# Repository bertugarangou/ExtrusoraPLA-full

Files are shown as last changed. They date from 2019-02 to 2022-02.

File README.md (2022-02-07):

# Extrusora PLA - full

IMG-20180929-WA0008

Extrusora de PLA controlada amb Arduino Mega 2560.

### Material
És necessari el següent material en especial:
* **Arduino Mega 2650 (REV3).** Original o rèplica.
* **Extrusora muntada.** Tremuga, compartiment amb vis-sens-fi, boquilla, sistema de refrigeració i sistema de bobinatge.
* **Motors pas-a-pas NEMA 17 o 23.** Per la bobina i pel vis sens fi.
* **Bobina.** Per guardar el fil obtingut.
* **Font d'alimentació.** Per l'Arduino, ventiladors i motors i resistència, de 230V, 12V i 9V/5.05V.

També és recomanable entendre el llenguatge de programació C i C++ i el funcionament de la plataforma Arduino i Arduino IDE.

#### Peces en 3D

 Algunes peces han sigut dissenyades des de zero i impreses en 3D (PLA), es poden trobar a [Parts3D](/Parts). Per dissenyar-les, s'ha utilitzat el programa [Autodesk Inventor Pro 2018/2019](https://www.autodesk.com/products/inventor/overview) i [Fusion 360](https://www.autodesk.com/products/fusion-360/overview), per tant, els fitxers penjats estan en el format ".ipt" o ".dwg" si es tracta d'un esquema (plànol). A més a més, estan penjades les mateixes peces en el format ".stl" per si no es tenen els anteriors programes. Els fitxers ".stl" (STereoLithography/Standard Tessellation Language) permeten ser carregats per un programa com [Ultimaker Cura](https://ultimaker.com/en/products/ultimaker-cura-software) (codi obert) o [Simplify3D](https://www.simplify3d.com/) (no és de codi obert) entre d'altres per convertir-se en un format llegible per les impresores i especificar certes configuracions per l'impresió posterior.
 
Altres peces, les que estan en contacte amb zones calentes, estan fetes amb acer o alumini. Tot i així, els suports de la base són fets de fusta aglomerada.

Alerta: els fitxers s'han d'obrir amb la versió 2019 per no tenir errors de visualització. Els fitxers ".dwg" s'han d'obrir amb Innventor millor que amb AutoCAD. Els programes d'Autodesk són de llicència gratuita educativa.

## Referències

* [Github](https://github.com/bertugarangou/ExtrusoraPLA/) - Sistema al núvol
* [Arduino](https://www.arduino.cc/) - Software
* [Arduino LiquidCrystal Library](https://www.arduino.cc/en/Reference/LiquidCrystal) - LLibreria d'Arduino per LCD
* [Arduino Tasker Library](https://github.com/joysfera/arduino-tasker) - Llibreria d'Arduino per l'ús multi-tasca

## Autors

* **Albert Garangou Culebras** - *Autor principal del projecte*

## Llicència

[LICENSE.md](LICENSE.md)

## Reconeixaments

* *Tutor del Treball de Recerca* - **Jordi Fanals Oriol**

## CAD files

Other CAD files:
Parts/Esquemes/0. Base/Estructura base.dwg
Parts/Esquemes/1. Extrusora/suport motor-1.dwg
Parts/Esquemes/1. Extrusora/tremuja.ipt
Parts/Models/0. Base/Estructura base.ipt
Parts/Models/1. Ventiladors/Ventilador bobina - boca.ipt
Parts/Models/1. Ventiladors/Ventilador bobina - suport.ipt
Parts/Models/1. Ventiladors/Ventilador controladores - boca.ipt
Parts/Models/1. Ventiladors/Ventilador controladores - suport.ipt
Parts/Models/1. Ventiladors/Ventilador filament - boca.ipt
Parts/Models/1. Ventiladors/Ventilador filament - cosPETIT.ipt
Parts/Models/1. Ventiladors/Ventilador tub - cos.ipt
Parts/Models/1. Ventiladors/Ventilador tub - guies.ipt
Parts/Models/1. Ventiladors/ventilador emergència inferior.ipt
Parts/Models/1. Ventiladors/ventilador emergència superior.ipt
Parts/Models/2. Extrusora/Motor extrusora - suport.ipt
Parts/Models/3. Detector fil/Detector fil - base.ipt
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

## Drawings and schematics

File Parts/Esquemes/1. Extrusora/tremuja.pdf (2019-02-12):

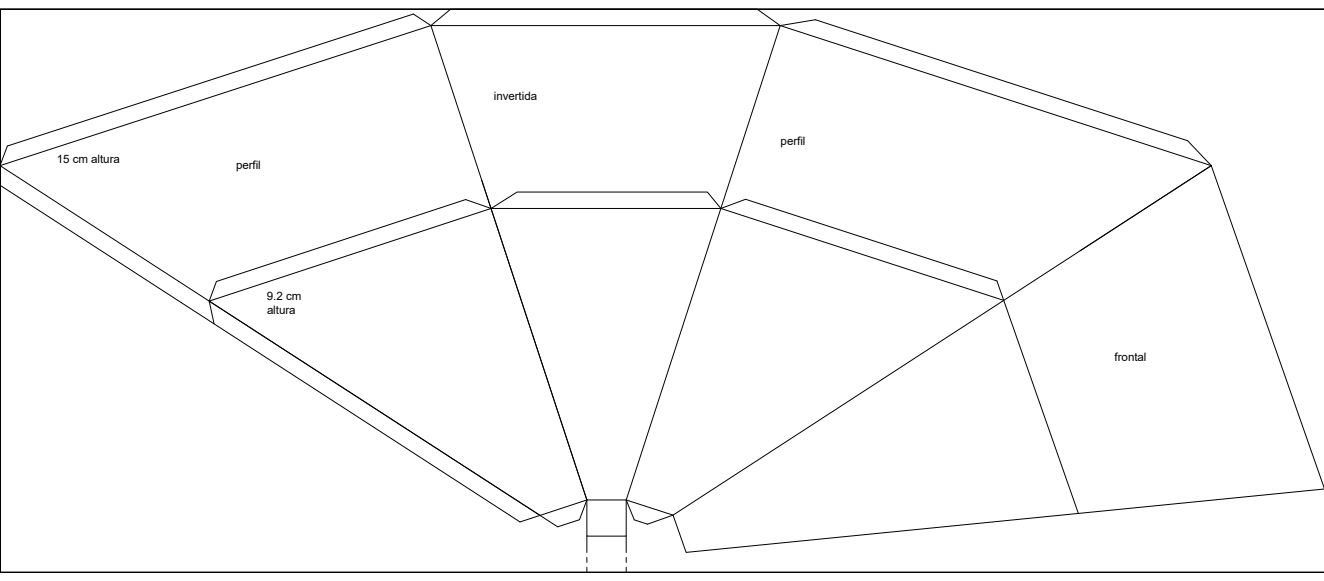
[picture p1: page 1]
rfil perfil; al 15 cm altura; 9.2 cm altura

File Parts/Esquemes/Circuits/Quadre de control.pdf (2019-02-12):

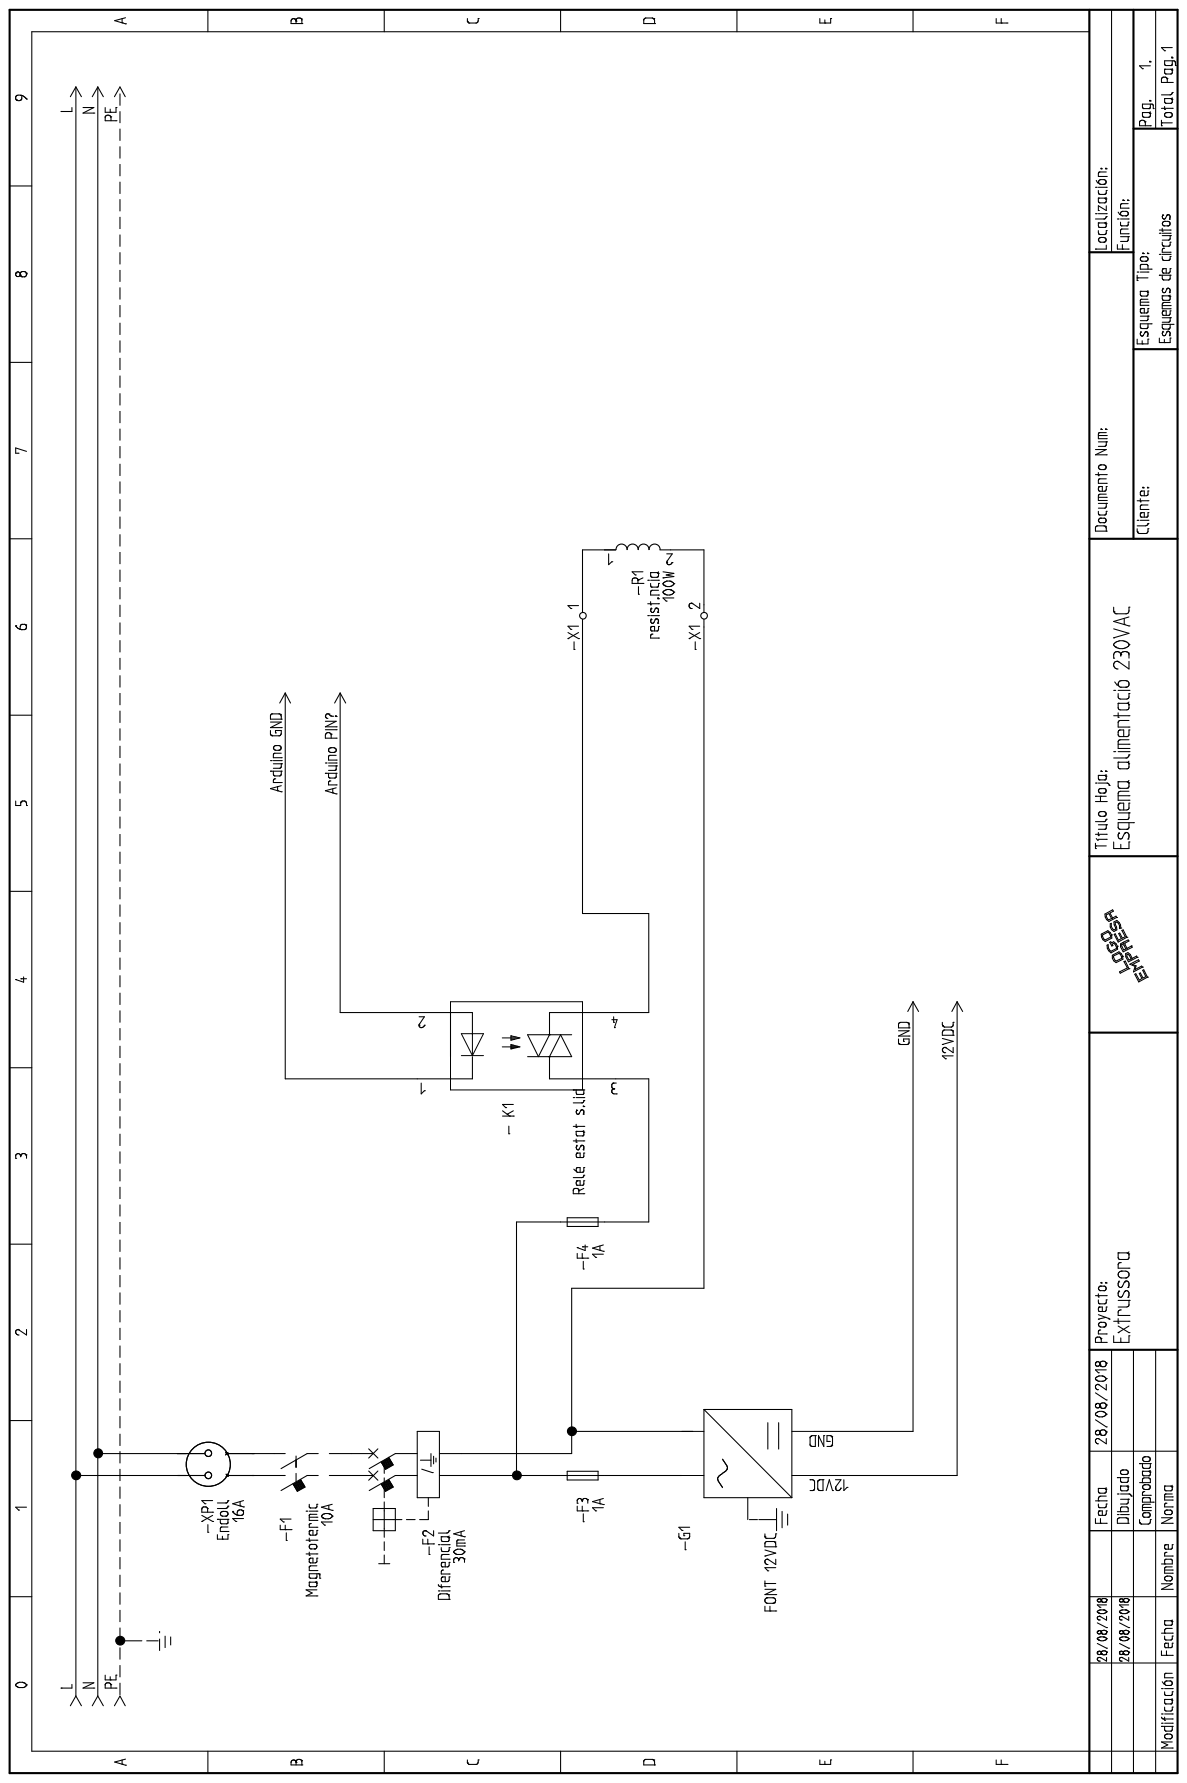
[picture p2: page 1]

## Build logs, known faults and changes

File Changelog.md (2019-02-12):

# Historial de versions

## Com funciona:
---
## Versió [NUMERO] (Data) - *CodeName*
 ## <No Funcional>

 ### Millores

  * Descripció
  * Descripció
      * Contingut

 ### Correccions
  * Descripció

 ### Errors coneguts
  * Descripció

 ### Més informació
  * "Commits"

---

## Versió 1 (15/10/2018) - *Inicial*

 ### Errors coneguts
  * El sensor IR detecta el fil per cualpa d'alguns llums d'habitacions.

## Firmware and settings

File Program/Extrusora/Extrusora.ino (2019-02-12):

/*
  Extrusora de PLA controlada per Arduino Mega 2560.

  Projecte:
  - https://github.com/bertugarangou/ExtrusoraPLA
  - Extrusora feta per Albert Garangou,
    com a Treball de Recerca a 2n de Batxillerat,
    curs 2018/2019, tutor: Jordi Fanals Oriol,
    codi amb Atom i Arduino-upload package.
  - Tots els drets reservats Albert Garangou Culebras (albertgarangou@gmail.com).
    Aquest codi és conegut com a "Proprietary software".
    Consulta el web origen per a més informació.
*/
/*+++++++++++++Llibreries++++++++++++++*/
#include <max6675.h>
MAX6675 tempSensorResistors(11, 12, 13);
MAX6675 tempSensorEnd(8, 9, 10);

#include <Wire.h>
#include <LiquidCrystal_I2C.h>
LiquidCrystal_I2C lcd(0x27, 16, 2); //PINS SDA i SCL lcd

/*+++++++++++++Llibreries++++++++++++++*/
/*++Declaració variables i constants+++*/
int const lcdUpdateFrequency = 250;  //1000-1500-x
int const tempReaderFrequency = 1000; //1000-1500-x
int const heaterFrequency = 0; //0 (instantari)-500-1000-x

int const INTFanFil = 6;
int const INTFanTube = 7;
int const relayFanFil = 52;
int const relayFanTube = 50;
int const STOPBtn = 30;
int const brunzidor = 51;
int const extruderStep = 25;
int const extruderDir = 26;
int const extruderEn = 28;
int const coilStep = 24;
int const coilDir = 27;
int const coilEn = 29;
int const filamentDetector = 36;
int const INTHeat = 53;
int const INTExtruder = 2;
int const INTExtruderRev = 3;
int const INTCoil = 4;
int const INTCoilRev = 5;
int const INTHeater = 49;
int const relayResistors = 32;

bool error = false;
bool canExtrude = false;
bool canCoil = false;

bool extrudingFwd = false;
bool extrudingRev = false;
bool coilingFwd = false;
bool coilingRev = false;

bool heatingPause = false;
bool heating = false;

bool canCoilByFilamentDetector = false;

int tempToShow;
float tempRest = 0.0;
float currentTempResistors = 0.0;
float currentTempEnd = 0.0;

float desiredTemp;
float desiredTempEnd;
float desiredTempResistors;

float tempResistors1 = 0.0;
float tempResistors2 = 0.0;
float tempResistors3 = 0.0;
float tempEnd1 = 0.0;
float tempEnd2 = 0.0;
float tempEnd3 = 0.0;
float finalTempEnd = 0.0;
float finalTempResistors = 0.0;

int const slowTempRange = 5;
int const tempMaxHot = -3; //-3
int tempResistorsRest;
int tempEndRest;

unsigned long ultimMillis_LCDMain = 0UL;
unsigned long ultimMillis_extruderStart = 0UL;
unsigned long ultimMillis_extruderStop = 0UL;
unsigned long ultimMillis_coilStart = 0UL;
unsigned long ultimMillis_coilStop = 0UL;
unsigned long ultimMillis_tempReader = 0UL;
unsigned long ultimMillis_heaterMain = 0UL;

int const extruderNEINSpeed = 6;
int const coilNEINSpeed = 20;

byte downArrow[8] = {
  B00100,
  B00100,
  B00100,
  B00100,
  B00100,
  B10101,
  B01110,
  B00100
};

byte upArrow[8] = {
  B00100,
  B01110,
  B10101,
  B00100,
  B00100,
  B00100,
  B00100,
  B00100
};

byte cross[8] = {
  B00000,
  B10001,
  B01010,
  B00100,
  B01010,
  B10001,
  B00000,
  B00000
};

byte check[8] = {
  B00000,
  B00000,
  B00001,
  B00010,
  B10100,
  B01000,
  B00000,
  B00000
};

byte rev[8] = {
  B00010,
  B00110,
  B01110,
  B11110,
  B01110,
  B00110,
  B00010,
  B00000
};

byte pause[8] = {
  B00000,
  B01010,
  B01010,
  B01010,
  B01010,
  B01010,
  B00000,
  B00000
};

/*++Declaració variables i constants+++*/
/*+++++++++++Declaracio funcions+++++++++++*/
void lcdController();
void fansController();
void extruderController();
void coilController();
void filamentDetectorFunction();
void heater();
void tempRead();
void errorProcedure();
void quickTempRead();
/*+++++++++++Declaracio funcions+++++++++++*/

void setup(){
  Serial.begin(9600); //inicia la depuració
  lcd.init();
  lcd.backlight();
  lcd.createChar(1, downArrow);
  lcd.createChar(2, upArrow);
  lcd.createChar(3, cross);
  lcd.createChar(4, check);
  lcd.createChar(5, rev);
  lcd.createChar(6, pause);

  lcd.clear();
  pinMode(INTFanFil, INPUT);
  pinMode(INTFanTube, INPUT);
  pinMode(STOPBtn, INPUT);
  pinMode(relayFanFil, OUTPUT);
  pinMode(relayFanTube, OUTPUT);
  pinMode(brunzidor, OUTPUT);
  pinMode(extruderStep, OUTPUT);
  pinMode(extruderDir, OUTPUT);
  pinMode(extruderEn, OUTPUT);
  pinMode(coilStep, OUTPUT);
  pinMode(coilDir, OUTPUT);
  pinMode(coilEn, OUTPUT);
  pinMode(filamentDetector, INPUT);
  pinMode(INTExtruder, INPUT);
  pinMode(INTExtruderRev, INPUT);
  pinMode(INTCoil, INPUT);
  pinMode(INTCoilRev, INPUT);
  pinMode(INTHeater, INPUT);
  pinMode(relayResistors, OUTPUT);
  digitalWrite(relayResistors, LOW);
}

void loop(){
 if(digitalRead(STOPBtn) == 0 || error == true){
  digitalWrite(brunzidor, HIGH);
  Serial.println("*****************************************");
  Serial.print("*   STOP");
  Serial.println(", entrant en mode emergència!   *");
  Serial.println("*                                       *");
  Serial.println("* NO DESCONECTAR FINS QUE ESTIGUI FRED! *");
  Serial.println("*****************************************");
  lcd.clear();
  lcd.print("!NO DESCONECTAR!");
  lcd.setCursor(9,1);
  lcd.print("ALERTA!");
  errorProcedure();
  while(true){//bucle infinit
  digitalWrite(brunzidor, LOW);
  lcd.noBacklight();
  quickTempRead();
  digitalWrite(brunzidor, HIGH);
  lcd.setCursor(0,1);
  lcd.print((int) finalTempResistors);
  lcd.print(char(223));
  lcd.print("/");
  lcd.print((int) finalTempEnd);
  lcd.print(char(223));
  lcd.backlight();
  delay(2000);
  }
 }
  else{ //funcionament estandart del programa (aka no hi ha cap error)
    lcdController();
    filamentDetectorFunction();
    fansController();
    tempRead();
    heater();
    extruderController();
    coilController();

  }
} //end

/*+++++++++++Definició funicons++++++++++++*/
void extruderController(){
  if (digitalRead(INTExtruder) == LOW && digitalRead(INTExtruderRev) == HIGH){//activat
    if(tempToShow > 169 && tempRest > -10){
      canCoil = true;
      if(millis() - ultimMillis_extruderStart >= extruderNEINSpeed){
        extrudingFwd = true;
        extrudingRev = false;
        digitalWrite(extruderStep, HIGH);
      if(millis() - ultimMillis_extruderStop >= extruderNEINSpeed){
        digitalWrite(extruderStep, LOW);
        ultimMillis_extruderStop = millis();
        ultimMillis_extruderStart = millis();
        }
      }
    }
  }
  else if(digitalRead(INTExtruder) == LOW && digitalRead(INTExtruderRev) == LOW){//invertit
    if(tempToShow > 169 && tempRest > -10){
      canCoil = false;
      if(millis() - ultimMillis_extruderStart >= extruderNEINSpeed){
        extrudingRev = true;
        extrudingFwd = false;
        digitalWrite(extruderDir, HIGH);
        digitalWrite(extruderStep, HIGH);
      if(millis() - ultimMillis_extruderStop >= extruderNEINSpeed){
        digitalWrite(extruderStep, LOW);
        digitalWrite(extruderDir, LOW);
        ultimMillis_extruderStop = millis();
        ultimMillis_extruderStart = millis();
        }
      }
    }
  }
  else{ //desactivat
    extrudingFwd = false;
    extrudingRev = false;
    canCoil = false;
  }
}

void coilController(){
  if (digitalRead(INTCoil) == LOW && digitalRead(INTCoilRev) == LOW){ // tots dos activats
    if(millis() - ultimMillis_coilStart >= coilNEINSpeed){
      coilingFwd = false;
      coilingRev = true;
      digitalWrite(coilStep, HIGH);
    if(millis() - ultimMillis_coilStop >= coilNEINSpeed){
      digitalWrite(coilStep, LOW);
      ultimMillis_coilStop = millis();
      ultimMillis_coilStart = millis();
      }
    }
  }
  else if(digitalRead(INTCoil) == LOW && digitalRead(INTCoilRev) == HIGH && canCoilByFilamentDetector == true){ // sense invertir direcció
    if(millis() - ultimMillis_coilStart >= coilNEINSpeed){
      coilingFwd = true;
      coilingRev = false;
      digitalWrite(coilDir, HIGH);
      digitalWrite(coilStep, HIGH);
      if(millis() - ultimMillis_coilStop >= coilNEINSpeed){
        digitalWrite(coilStep, LOW);
        digitalWrite(coilDir, LOW);
        ultimMillis_coilStop = millis();
        ultimMillis_coilStart = millis();
      }
    }
  }
  else{
    coilingFwd = false;
    coilingRev = false;
  }
}

void fansController(){
  if(digitalRead(INTFanFil) == LOW){ //quan s'activa l'interruptor adequat
    digitalWrite(relayFanFil, LOW); //activar relé ventilador
    //Serial.println("Ventilador: Filament **ON**");
  }
  else{ //sinó
    digitalWrite(relayFanFil, HIGH); //desactiva'l
    //Serial.println("Ventilador: Filament **OFF**");
  }

  if(digitalRead(INTFanTube) == LOW){  //si s'activa l'interruptor adequat
    digitalWrite(relayFanTube, LOW);  //activa el relé del ventilador
    //Serial.println("Ventilador: Extrusora **ON**");
  }
  else{ //sinó
    digitalWrite(relayFanTube, HIGH);  //desactiva'l
    //Serial.println("Ventilador: Extrusora **OFF**");
  }
}

void lcdController(){
  if(millis() - ultimMillis_LCDMain >= lcdUpdateFrequency){
    lcd.setCursor(0,0);
    lcd.print((int) tempToShow);
    lcd.print("/");
    lcd.print((int) desiredTemp);
    lcd.print(char(223));
    lcd.print("  ");

    if(canExtrude == true){ //estat general
      lcd.setCursor(10,0);
      lcd.print(" LLEST");
    }
    else if(canExtrude == false && heating == true){
      lcd.setCursor(10,0);
      lcd.print("ESPERA");
    }

    else{
      lcd.setCursor(10, 0);
      lcd.print(" PAUSA");
    }

    if(extrudingFwd == true){ //estat extrusor
      lcd.setCursor(0,1);
      lcd.print("E:");
      lcd.write(4);
      lcd.print(" ");
    }
    else if(extrudingRev == true){
      lcd.setCursor(0,1);
      lcd.print("E:");
      lcd.write(5);
      lcd.write(5);
    }
    else{
      lcd.setCursor(0,1);
      lcd.print("E:");
      lcd.write(3);
      lcd.print(" ");
    }

    if(coilingFwd == true){  //estat bobina
      lcd.setCursor(11,1);
      lcd.print("B:");
      lcd.write(4);
      lcd.print(" ");
    }
    else if(coilingRev == true){
      lcd.setCursor(11,1);
      lcd.print("B:");
      lcd.write(5);
      lcd.write(5);
    }
     else{
      lcd.setCursor(11,1);
      lcd.print("B:");
      lcd.write(3);
      lcd.print(" ");
    }

    if(heating == true && heatingPause == false){  //estat heating
      lcd.setCursor(6,1);
      lcd.print("H:");
      lcd.write(4);
    }
    else if(heating == true && heatingPause == true){
      lcd.setCursor(6,1);
      lcd.print("H:");
      lcd.write(6);
    }
    else{
      lcd.setCursor(6,1);
      lcd.print("H:");
      lcd.write(3);
    }


      if(coilingFwd == true){
      lcd.setCursor(15,1);
      lcd.write(2);
      }
      else if(coilingRev == true){
      lcd.setCursor(15,1);
      lcd.write(1);
      }
    else{
      lcd.setCursor(15,1);
      lcd.print(" ");
      }

    ultimMillis_LCDMain = millis();
  }
}

void filamentDetectorFunction(){
  if(extrudingFwd == true){
    if(digitalRead(filamentDetector) == LOW){
      canCoilByFilamentDetector = true;
    }
    else{
      canCoilByFilamentDetector = false;
    }
  }
}

void heater(){
  if(digitalRead(INTHeater) == LOW){
    desiredTemp = 180;
    desiredTempResistors = 210;
    desiredTempEnd = 155;

    //if(millis() - ultimMillis_heaterMain >= heaterFrequency){
    tempRest = desiredTemp - tempToShow;
      if(tempToShow > 0 && tempRest > 1){  //escalfant de lluny
        digitalWrite(relayResistors, HIGH);
        heating = true;
        heatingPause = false;
      }
      else if(tempRest <= tempMaxHot){  //massa alta
        digitalWrite(relayResistors, LOW);
        heating = true;
        heatingPause = true;
        digitalWrite(relayFanTube, LOW);
      }
      else if(tempToShow >0 && tempRest <= 1 && tempRest > -3){ // pausant temperatura està ok
        digitalWrite(relayResistors, LOW);
        heatingPause = true;
        heating = true;
      }
      else{ //no escalfa
        digitalWrite(relayResistors, LOW);
        heating = false;
        heatingPause = false;
      }
    //}
  }
  else if (digitalRead(INTHeater) == HIGH){
    desiredTempEnd = 0;
    desiredTempResistors = 0;
    desiredTemp = 0;
    digitalWrite(relayResistors, LOW);
    heating = false;
  }
}

void errorProcedure(){
  digitalWrite(relayFanFil, LOW);
  digitalWrite(relayFanTube, LOW);
  digitalWrite(relayResistors, LOW);
}

void quickTempRead(){
  tempEnd1 = tempSensorEnd.readCelsius();
  tempResistors1 = tempSensorResistors.readCelsius();
  delay(500);
  tempEnd2 = tempSensorEnd.readCelsius();
  tempResistors2 = tempSensorResistors.readCelsius();
  delay(500);
  tempEnd3 = tempSensorEnd.readCelsius();
  tempResistors3 = tempSensorResistors.readCelsius();
  finalTempEnd = (tempEnd1 + tempEnd2 + tempEnd3) / 3;
  finalTempResistors = (tempResistors1 + tempResistors2 + tempResistors3) / 3;

}

void tempRead(){
  if(millis() - ultimMillis_tempReader >= tempReaderFrequency){
    currentTempEnd = tempSensorEnd.readCelsius();
    currentTempResistors = tempSensorResistors.readCelsius();
    Serial.println(currentTempEnd);
    Serial.println(currentTempResistors);


    tempToShow = (currentTempEnd * 70 + currentTempResistors * 30) / 100;
    Serial.println(tempToShow);
    Serial.println("-------------");
    ultimMillis_tempReader = millis();
  }
  if(currentTempEnd >= 155 && currentTempEnd <= 175 && currentTempResistors >= 210 && currentTempResistors <= 235){
    canExtrude = true;
  }
  else if(tempToShow >= 195 || currentTempEnd > 176 || currentTempResistors > 236){
    error = true;
  }
  else {
    canExtrude = false;
  }
}
/*+++++++++++Definició funicons++++++++++++*/

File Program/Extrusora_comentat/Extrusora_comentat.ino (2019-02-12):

/*
  Extrusora de PLA controlada per Arduino Mega 2560.

  Projecte:
  - https://github.com/bertugarangou/ExtrusoraPLA
  - Extrusora feta per Albert Garangou,
    com a Treball de Recerca a 2n de Batxillerat,
    curs 2018/2019, tutor: Jordi Fanals Oriol,
    codi amb Atom i Arduino-upload package.
  - Tots els drets reservats Albert Garangou Culebras (albertgarangou@gmail.com).
    Aquest codi és conegut com a "Proprietary software".
    Consulta el web origen per a més informació.


  -Aquesta versió del programa, conté totes les línies necessàries comentades.
  -Funciona idènticament al original, però serveix per entendre més a fons el codi.
  -S'actualitza al mateix moment que l'original, també està sota la mateixa llicència i normes.

*/
/*+++++++++++++Llibreries++++++++++++++*/
#include <max6675.h>  //importa llibreria pel modul de temperatura
MAX6675 tempSensorResistors(11, 12, 13);  //declara sensor temp1
MAX6675 tempSensorEnd(8, 9, 10);  //declara sensor temp2

#include <Wire.h> //importa la llibreria per sensors I2C
#include <LiquidCrystal_I2C.h>  //importa llibreria per la pantalla I2C
LiquidCrystal_I2C lcd(0x27, 16, 2); //PINS SDA i SCL lcd

/*+++++++++++++Llibreries++++++++++++++*/
/*++Declaració variables i constants+++*/
//Frequüències d'actualització de funcions
int const lcdUpdateFrequency = 250;  //250  //frequüència pantalla lcd
int const tempReaderFrequency = 1000; //1000  //frequüència lectura temperatura
int const heaterFrequency = 0; //0  //frequüència accions escalfador
//entrades i sortides
int const INTExtruder = 2;
int const INTExtruderRev = 3;
int const INTCoil = 4;
int const INTCoilRev = 5;
int const INTFanFil = 6;
int const INTFanTube = 7;
int const coilStep = 24;
int const extruderStep = 25;
int const extruderDir = 26;
int const coilDir = 27;
int const extruderEn = 28;
int const coilEn = 29;
int const STOPBtn = 30;
int const relayResistors = 32;
int const filamentDetector = 36;
int const INTHeater = 49;
int const relayFanTube = 50;
int const brunzidor = 51;
int const relayFanFil = 52;
int const INTHeat = 53;

//booleans d'estat
bool error = false; //boolean per avisar quan tingui lloc un error

bool extrudingFwd = false;  //extrudint
bool extrudingRev = false;  //extrudint del revés
bool coilingFwd = false;  //bobinant
bool coilingRev = false;  //bobinant del revés

bool heating = false; //estableix que s'està extrudint
bool heatingPause = false;  //estableix que l'extrussió està en pausa

//booleans de comprovació
bool canExtrude = false;  //comprova si es pot extrudir
bool canCoil = false; //comprova si es pot bobinar

bool canCoilByFilamentDetector = false; //comprova si el detector IR permet bobinar

//valors de temperatures
int tempToShow; //temp per mostrar a la lcd
float currentTempResistors = 0.0; //temp actual de les resistències
float currentTempEnd = 0.0; //temp actual final tub

float desiredTemp;  //temp desitjat total
float desiredTempEnd; //temp desithat final tub
float desiredTempResistors; //temp desitjat resistències

int const slowTempRange = 5;  //marge de frenada (coat) quan s'aproxima a la temp desitjada

int tempResistorsRest;  //calcul |temp actual resistències - temp volguda resistències|
int tempEndRest;  //calcul | temp acual tub - temp volguda final tub
float tempRest = 0.0; //calcul |temp acual - temp volguda|
//valors de temperatures per càlculs ràpids
float tempResistors1 = 0.0; //lectures temp 1
float tempResistors2 = 0.0; //2
float tempResistors3 = 0.0; //3
float tempEnd1 = 0.0; //1
float tempEnd2 = 0.0; //2
float tempEnd3 = 0.0; //3

float finalTempEnd = 0.0; //mitjana de les 3 lectures de temp del final del tub
float finalTempResistors = 0.0; //mitjana de les 3 lectures de temp de les resistències

//ultim timestamp pròpi d'execució de funcions
unsigned long ultimMillis_LCDMain = 0UL;  //últim cop (temps en milisegons) que s'ha executat la funció
unsigned long ultimMillis_extruderStart = 0UL;
unsigned long ultimMillis_extruderStop = 0UL;
unsigned long ultimMillis_coilStart = 0UL;
unsigned long ultimMillis_coilStop = 0UL;
unsigned long ultimMillis_tempReader = 0UL;
unsigned long ultimMillis_heaterMain = 0UL;

//velocitats dels motors
int const extruderEmulatedSpeed = 6;  //6 // temps entre l'activació de la bobina del motor i la desactivació
int const coilEmulatedSpeed = 20; //20

//matrius de caràcters personalitzats lcd
byte downArrow[8] = { //caràcter lcd fletxa senyalant cap a baix
  B00100,
  B00100,
  B00100,
  B00100,
  B00100,
  B10101,
  B01110,
  B00100
};

byte upArrow[8] = { //caràcter lcd fletxa senyalant cap a dalt
  B00100,
  B01110,
  B10101,
  B00100,
  B00100,
  B00100,
  B00100,
  B00100
};

byte cross[8] = { //caràcter lcd creu "X"
  B00000,
  B10001,
  B01010,
  B00100,
  B01010,
  B10001,
  B00000,
  B00000
};

byte check[8] = { //caràcter lcd "tick"
  B00000,
  B00000,
  B00001,
  B00010,
  B10100,
  B01000,
  B00000,
  B00000
};

byte rev[8] = { //caràcter lcd signe revés "<<"
  B00010,
  B00110,
  B01110,
  B11110,
  B01110,
  B00110,
  B00010,
  B00000
};

byte pause[8] = { //caràcter lcd pausa "||"
  B00000,
  B01010,
  B01010,
  B01010,
  B01010,
  B01010,
  B00000,
  B00000
};
/*++Declaració variables i constants+++*/
/*+++++++++++Declaracio funcions+++++++++++*/
void lcdController();  //funció per mostrar informació a la pantalla
void fansController();  //funció per activar i desactivar els ventiladors
void extruderController();  //funció per controlar l'extrusor
void coilController();  //funció per controlar la bobina
void filamentDetectorFunction();  //funció per coneixer i enviar l'estat del sensor IR de penajment
void heater();  //funció per escalfar
void tempRead();  //funció per llegir la temp i calcular la mitjana no proporcional de les dues lectures
void errorProcedure();  //funció amb els procediemnts per quan hi ha una emergència
void quickTempRead(); //funció per llegir 3 vegades la temp i fer-ne la mitjana (només utilitzada quan hi ha un error)
/*+++++++++++Declaracio funcions+++++++++++*/
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

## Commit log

2019-02-12 first copy
    [Base auxiliar - encaix estructura.ipt, Base auxiliar - esquadra.ipt, Bobinatge - acoplament eix.ipt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]
2019-02-12 circuit clean
